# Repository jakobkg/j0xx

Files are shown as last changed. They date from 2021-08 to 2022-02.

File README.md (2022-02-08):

# j0xx
A controller inspired by the Frame1 and Smashbox controllers
image of the controller

## Case
### BOM
 - 36 M2 screws, countersunk head recommended
   - 28x 10mm
   - 8x 5mm
 - 18 M2 threaded spacers
   - 18x 10mm
 - 35 pieces of wire, stranded or solid core

## PCBs
The PCB files in this repository are all made using KiCad 6, and may not work properly in earlier versions. Most files are only plain PCBs, but the "main board" files also hold part numbers and information needed to place an order including assembly through JLCPCB.

## Build notes
***Due to height constraints, surface mounted LEDs can not be used along with low profile Choc switches in this iteration of the design***

The controller case is designed to be made out of cut sheets of material, such as laser cut wood/acrylic or metal.
I recommend a thickness of 3mm for the top plate for use with low profile Choc switches, and 6mm for use with regular MX switches to ensure keycaps protrude nicely without the sides of the switches being exposed.
The switch mounting plate needs to be 1.5mm thick to fit the Cherry MX/Kailh Choc design specs and ensure a good fit, thinner plates may cause poor mounting and thicker plates will interfere with Choc switch mounting.

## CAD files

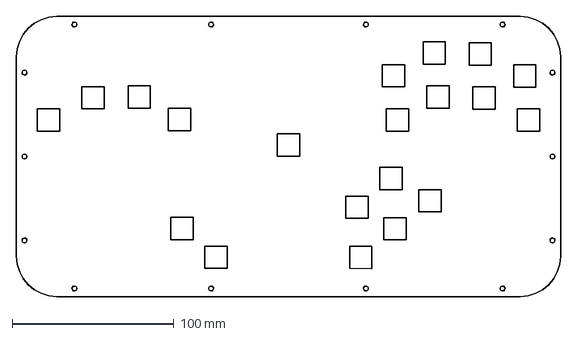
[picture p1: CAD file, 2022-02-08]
case/switchplate_choc.dxf
336.4 x 173.2 mm

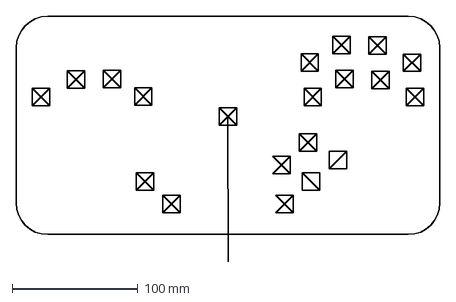
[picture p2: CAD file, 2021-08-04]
switchplate.dxf
336.4 x 194.8 mm

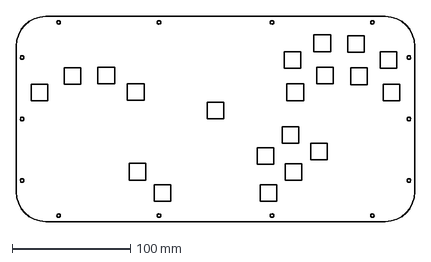
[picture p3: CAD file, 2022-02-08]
case/switchplate_MX.dxf
336.4 x 173.2 mm

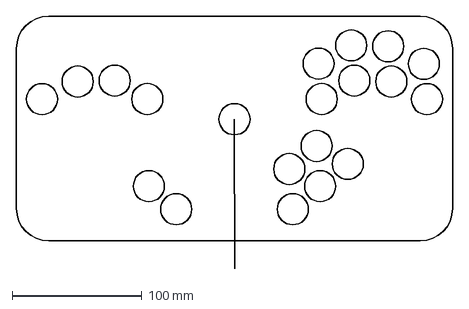
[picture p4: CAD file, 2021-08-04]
top.dxf
336.4 x 194.8 mm

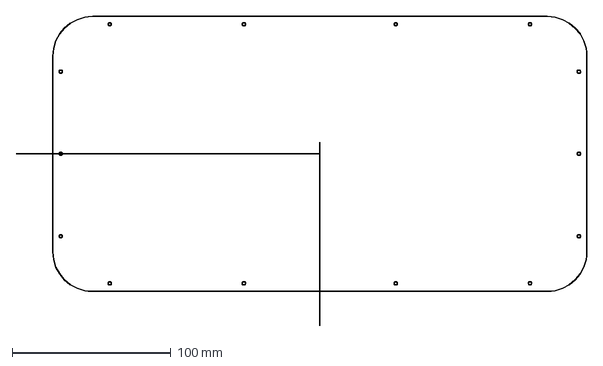
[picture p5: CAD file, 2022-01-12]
case/bottom.dxf
359.5 x 194.8 mm

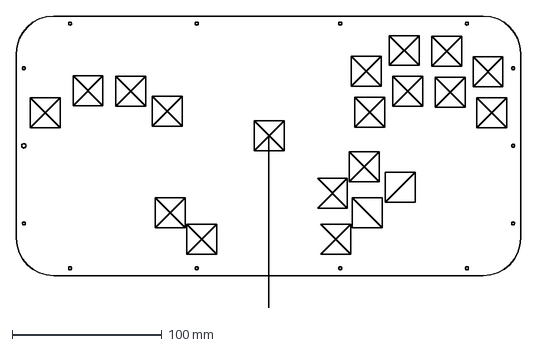
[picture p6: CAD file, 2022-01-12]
case/top.dxf
336.4 x 194.8 mm

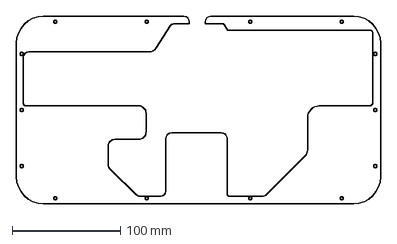
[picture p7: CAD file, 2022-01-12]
case/body.dxf
336.4 x 173.2 mm

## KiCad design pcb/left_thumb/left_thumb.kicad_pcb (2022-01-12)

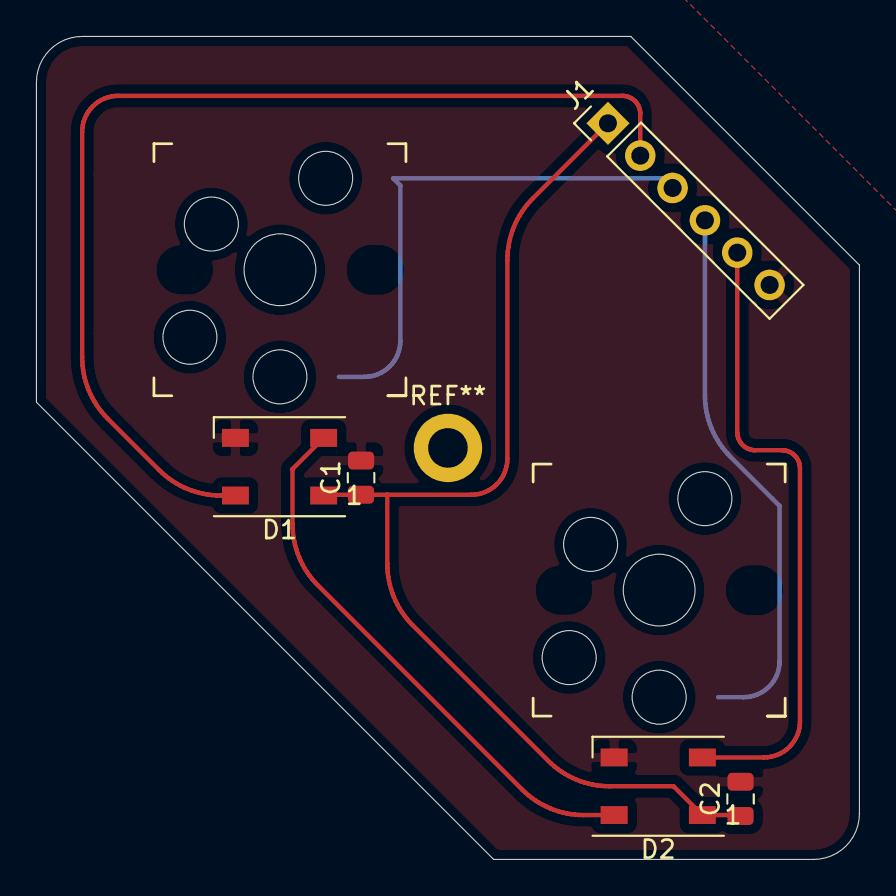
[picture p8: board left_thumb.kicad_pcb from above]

Board: 2 copper layers, 45.7 x 45.7 mm, 7 parts (0 on the bottom side), 7 nets.

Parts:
C1, C2: C; C_0805_2012Metric
D1, D2: WS2812B; LED_WS2812B_PLCC4_5.0x5.0mm_P3.2mm
J1: Conn_01x06; PinHeader_1x06_P2.54mm_Vertical
SW1, SW2: SW_Push; MX+Choc_socket

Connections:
+5V: C1.1, C2.1, D1.1, D2.1, J1.1
BTN_MODX: J1.3, SW1.1
BTN_MODY: J1.4, SW2.1
GND: C1.2, C2.2, D1.3, D2.3, J1.6, SW1.2, SW2.2
LED_IN: D1.4, J1.2
LED_OUT: D2.2, J1.5
unnamed: D1.2, D2.4

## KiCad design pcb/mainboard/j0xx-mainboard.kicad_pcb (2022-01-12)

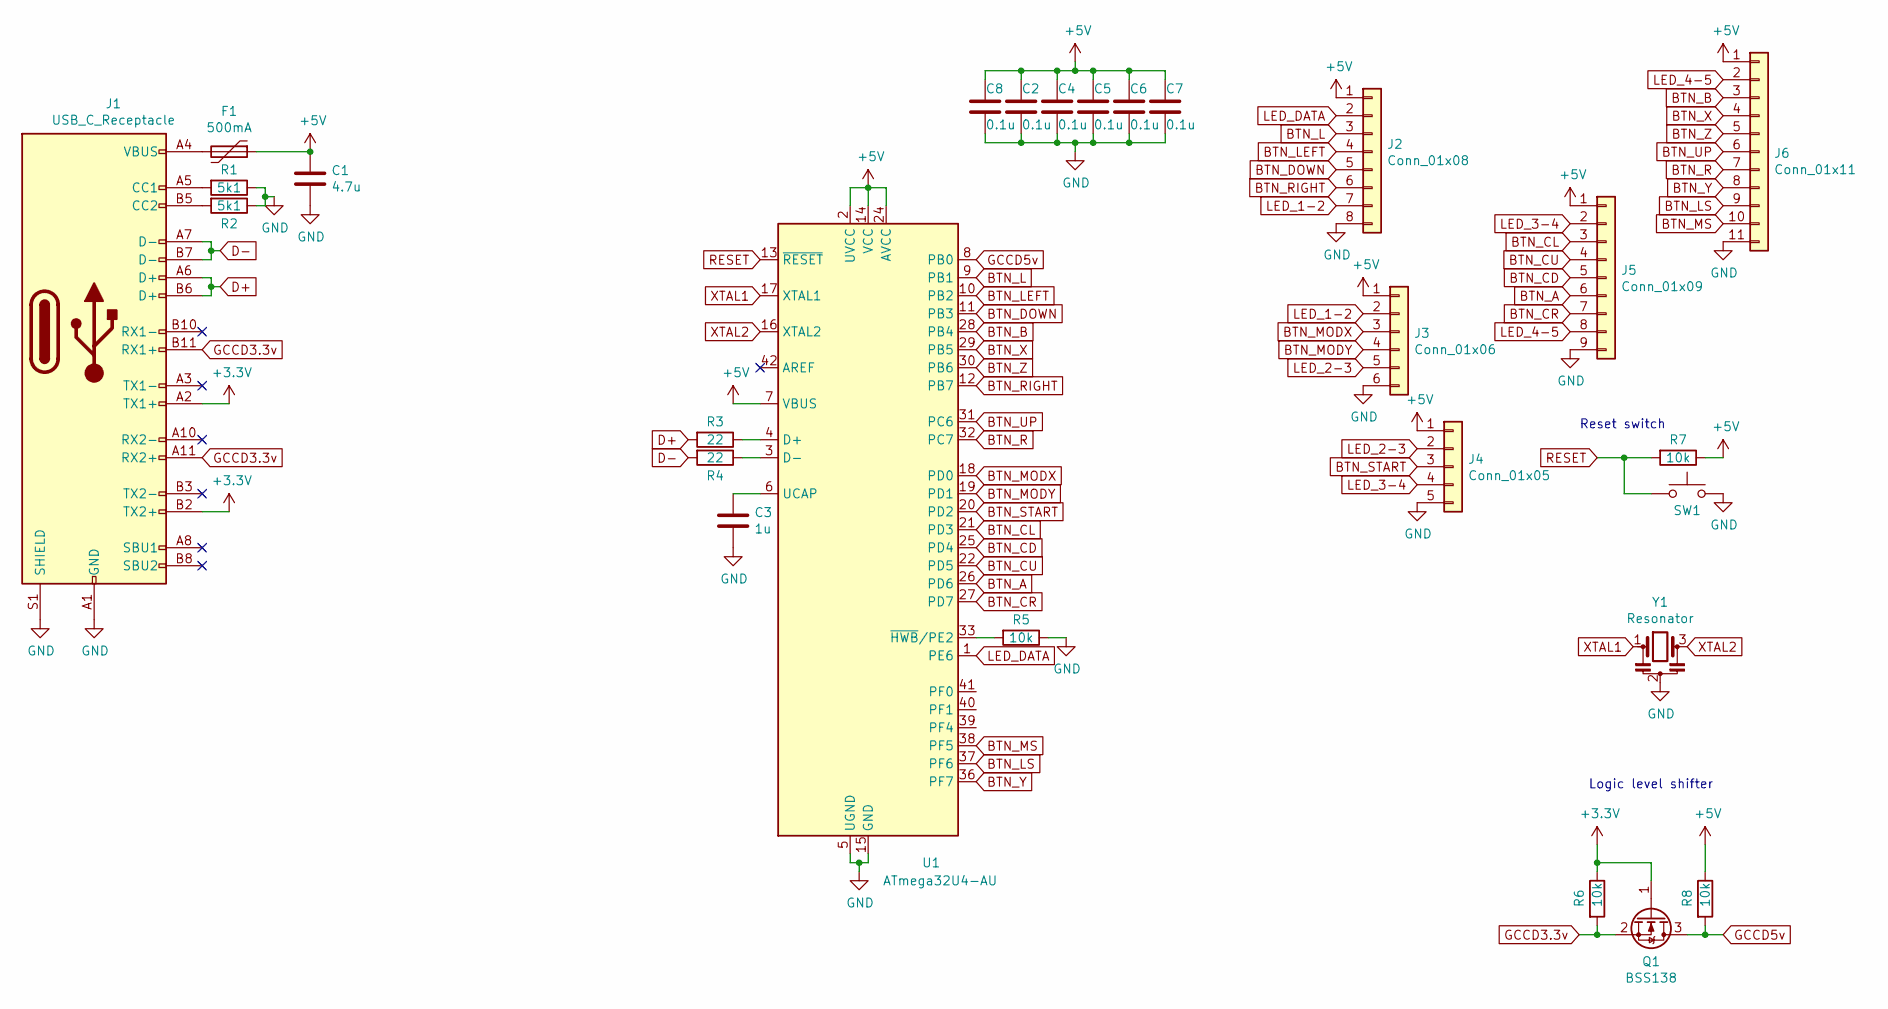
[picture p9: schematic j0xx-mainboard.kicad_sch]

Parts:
C1: 4.7u; C_0805_2012Metric; LCSC C1779
C2, C4, C5, C6, C7, C8: 0.1u; C_0805_2012Metric; LCSC C28233
C3: 1u; C_0805_2012Metric; LCSC C28323
F1: 500mA; Fuse_1206_3216Metric; LCSC C261952
J1: USB_C_Receptacle; USB_C_LCSC_C456013; LCSC C456013
J2: Conn_01x08; PinHeader_1x08_P2.54mm_Vertical
J3: Conn_01x06; PinHeader_1x06_P2.54mm_Vertical
J4: Conn_01x05; PinHeader_1x05_P2.54mm_Vertical
J5: Conn_01x09; PinHeader_1x09_P2.54mm_Vertical
J6: Conn_01x11; PinHeader_1x11_P2.54mm_Vertical
Q1: BSS138; SOT-23; LCSC C427380
R1, R2: 5k1; R_0805_2012Metric; LCSC C27834
R3, R4: 22; R_0805_2012Metric; LCSC C17561
R5, R6, R7, R8: 10k; R_0805_2012Metric; LCSC C17414
SW1: reset; TestPoint_2Pads_Pitch2.54mm_Drill0.8mm
U1: ATmega32U4-AU; TQFP-44_10x10mm_P0.8mm; LCSC C112161
Y1: Resonator; Resonator_SMD_Murata_CSTxExxV-3Pin_3.0x1.1mm; LCSC C341521

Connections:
+3V3: J1.A2 (TX1+), J1.B2 (TX2+), Q1.1 (G), R6.1
+5V: C1.1, C2.1, C4.1, C5.1, C6.1, C7.1, C8.1, F1.1, J2.1, J3.1, J4.1, J5.1, J6.1, R7.1, R8.1, U1.2 (UVCC), U1.7 (VBUS), U1.14 (VCC), U1.24 (AVCC), U1.34 (VCC), U1.44 (AVCC)
BTN_A: J5.6, U1.26 (PD6)
BTN_B: J6.3, U1.28 (PB4)
BTN_CD: J5.5, U1.25 (PD4)
BTN_CL: J5.3, U1.21 (PD3)
BTN_CR: J5.7, U1.27 (PD7)
BTN_CU: J5.4, U1.22 (PD5)
BTN_DOWN: J2.5, U1.11 (PB3)
BTN_L: J2.3, U1.9 (PB1)
BTN_LEFT: J2.4, U1.10 (PB2)
BTN_LS: J6.9, U1.37 (PF6)
BTN_MODX: J3.3, U1.18 (PD0)
BTN_MODY: J3.4, U1.19 (PD1)
BTN_MS: J6.10, U1.38 (PF5)
BTN_R: J6.7, U1.32 (PC7)
BTN_RIGHT: J2.6, U1.12 (PB7)
BTN_START: J4.3, U1.20 (PD2)
BTN_UP: J6.6, U1.31 (PC6)
BTN_X: J6.4, U1.29 (PB5)
BTN_Y: J6.8, U1.36 (PF7)
BTN_Z: J6.5, U1.30 (PB6)
D+: J1.A6 (D+), J1.B6 (D+), R3.2
D-: J1.A7 (D-), J1.B7 (D-), R4.2
GCCD3.3v: J1.A11 (RX2+), J1.B11 (RX1+), Q1.2 (S), R6.2
GCCD5v: Q1.3 (D), R8.2, U1.8 (PB0)
GND: C1.2, C2.2, C3.2, C4.2, C5.2, C6.2, C7.2, C8.2, J1.A1 (GND), J1.A12 (GND), J1.B1 (GND), J1.B12 (GND), J1.S1 (SHIELD), J2.8, J3.6, J4.5, J5.9, J6.11, R1.1, R2.1, R5.1, SW1.2, U1.5 (UGND), U1.15 (GND), U1.23 (GND), U1.35 (GND), U1.43 (GND), Y1.2
LED_1-2: J2.7, J3.2
LED_2-3: J3.5, J4.2
LED_3-4: J4.4, J5.2
LED_4-5: J5.8, J6.2
LED_DATA: J2.2, U1.1 (PE6)
unnamed: C3.1, U1.6 (UCAP)
unnamed: F1.2, J1.A4 (VBUS), J1.A9 (VBUS), J1.B4 (VBUS), J1.B9 (VBUS)
unnamed: J1.A5 (CC1), R1.2
unnamed: J1.B5 (CC2), R2.2
unnamed: R3.1, U1.4 (D+)
unnamed: R4.1, U1.3 (D-)
unnamed: R5.2, U1.33 (~HWB/PE2)
RESET: R7.2, SW1.1, U1.13 (~RESET)
XTAL1: U1.17 (XTAL1), Y1.1
XTAL2: U1.16 (XTAL2), Y1.3

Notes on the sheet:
Logic level shifter
Reset switch

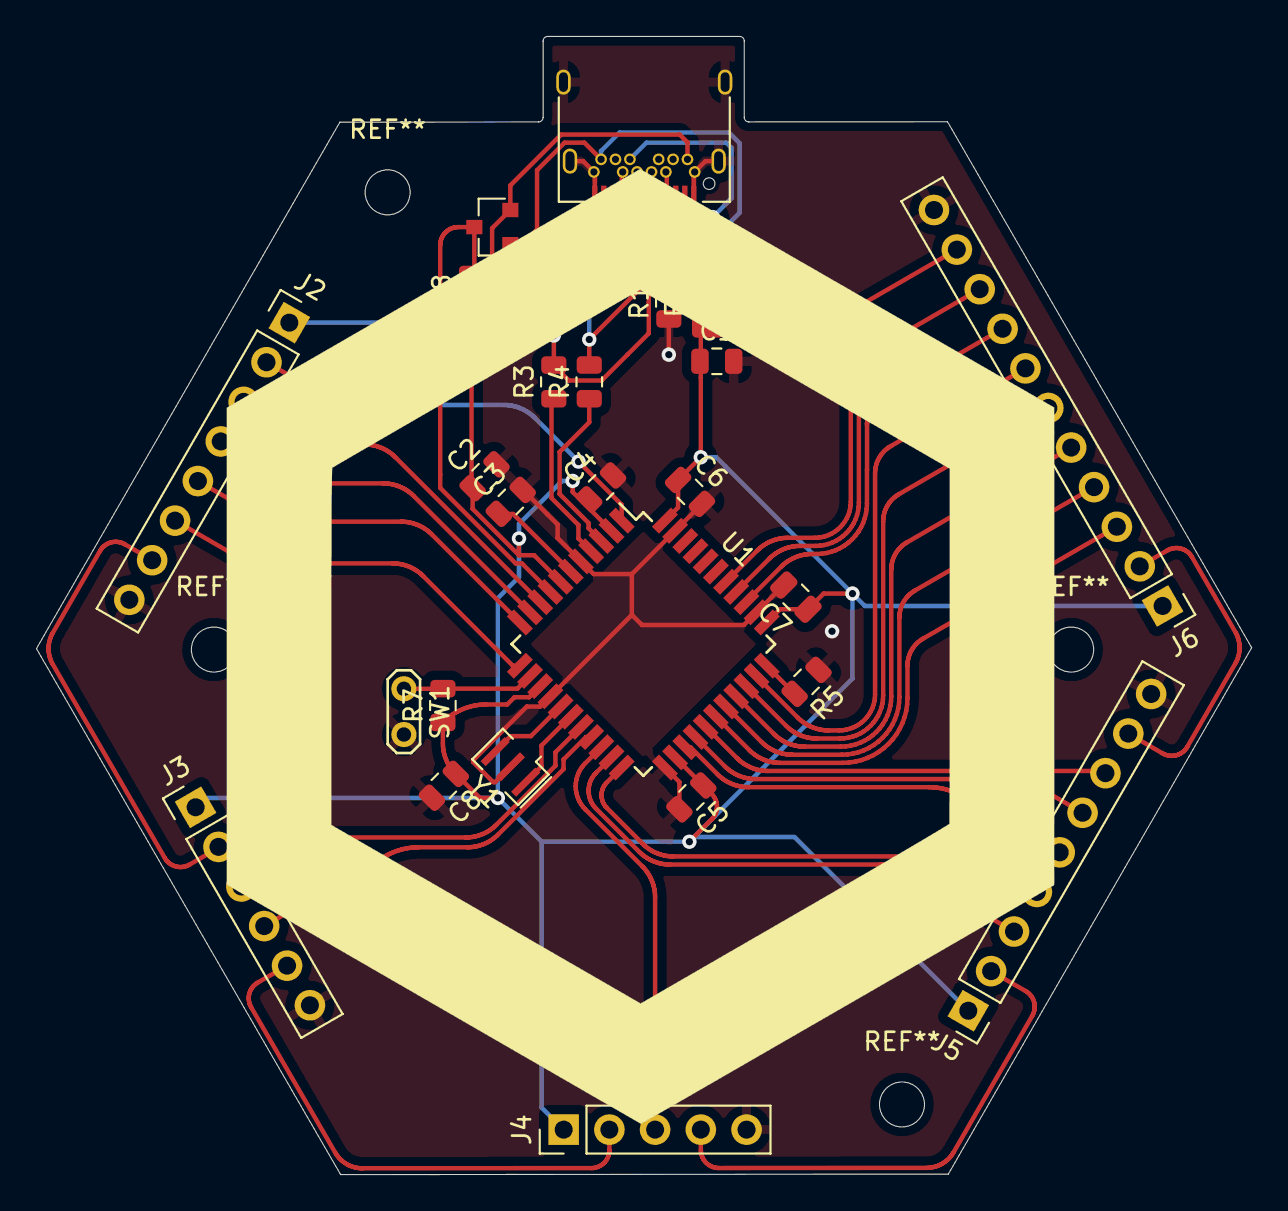
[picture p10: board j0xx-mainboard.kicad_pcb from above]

Board: 2 copper layers, 67.5 x 63.2 mm, 27 parts (0 on the bottom side), 42 nets.

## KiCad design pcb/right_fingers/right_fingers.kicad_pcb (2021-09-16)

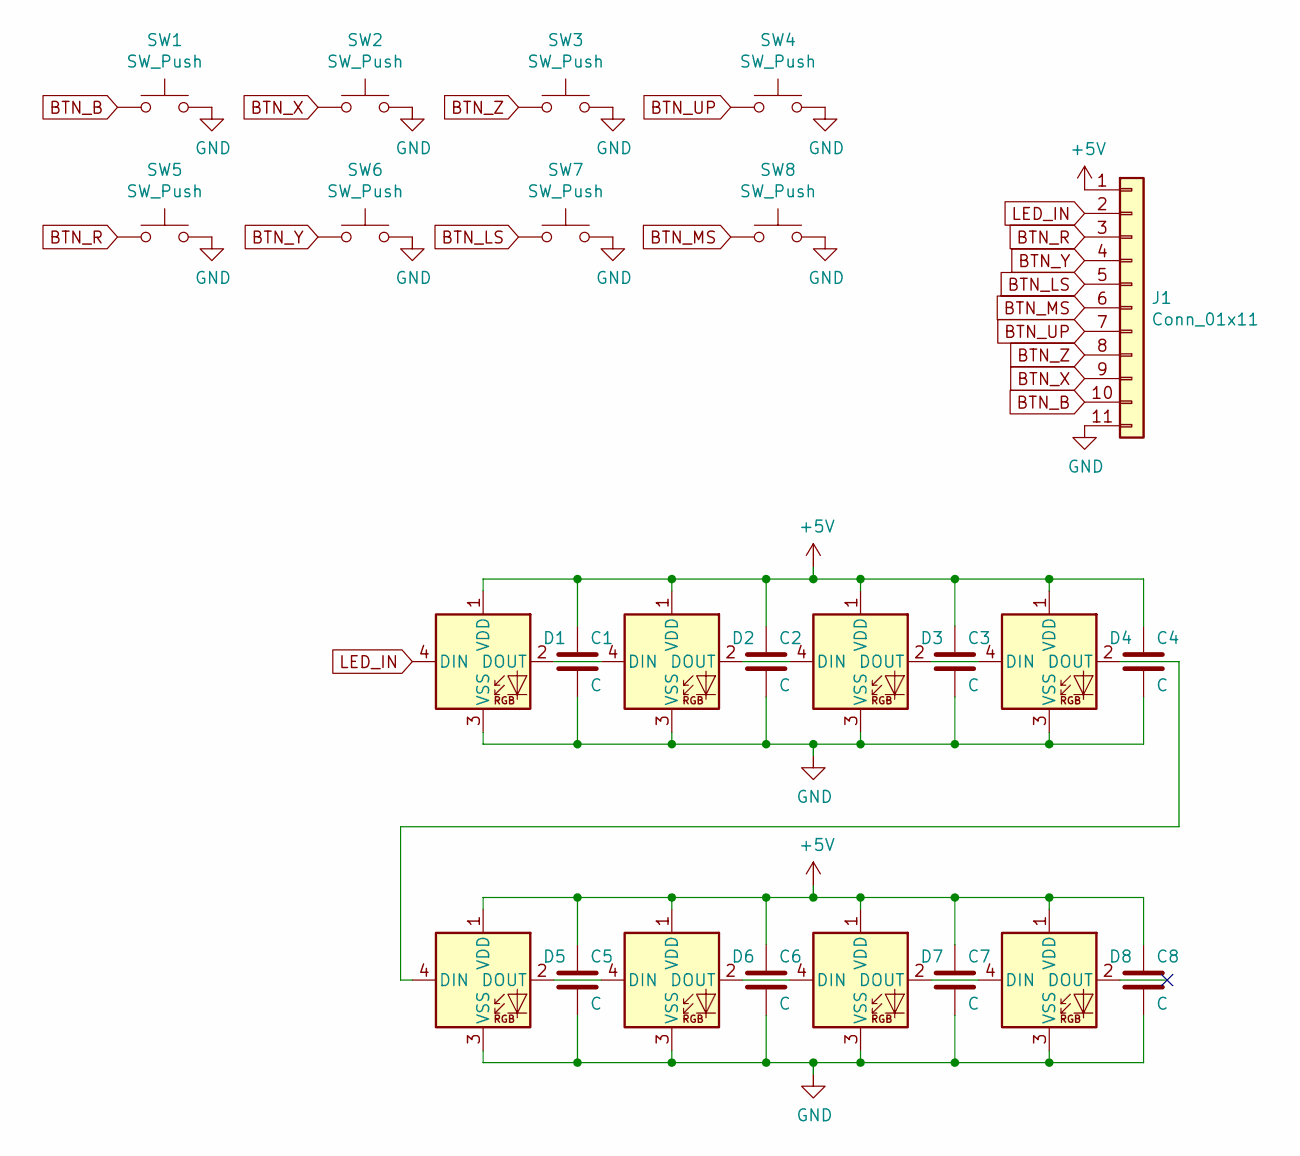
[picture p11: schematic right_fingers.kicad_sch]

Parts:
C1, C2, C3, C4, C5, C6, C7, C8: C; C_0805_2012Metric
D1, D2, D3, D4, D5, D6, D7, D8: WS2812B; LED_WS2812B_PLCC4_5.0x5.0mm_P3.2mm
J1: Conn_01x11; PinHeader_1x11_P2.54mm_Vertical
SW1, SW2, SW3, SW4, SW5, SW6, SW7, SW8: SW_Push; MX+Choc_socket

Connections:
+5V: C1.1, C2.1, C3.1, C4.1, C5.1, C6.1, C7.1, C8.1, D1.1 (VDD), D2.1 (VDD), D3.1 (VDD), D4.1 (VDD), D5.1 (VDD), D6.1 (VDD), D7.1 (VDD), D8.1 (VDD), J1.1
BTN_B: J1.10, SW1.1
BTN_LS: J1.5, SW7.1
BTN_MS: J1.6, SW8.1
BTN_R: J1.3, SW5.1
BTN_UP: J1.7, SW4.1
BTN_X: J1.9, SW2.1
BTN_Y: J1.4, SW6.1
BTN_Z: J1.8, SW3.1
GND: C1.2, C2.2, C3.2, C4.2, C5.2, C6.2, C7.2, C8.2, D1.3 (VSS), D2.3 (VSS), D3.3 (VSS), D4.3 (VSS), D5.3 (VSS), D6.3 (VSS), D7.3 (VSS), D8.3 (VSS), J1.11, SW1.2, SW2.2, SW3.2, SW4.2, SW5.2, SW6.2, SW7.2, SW8.2
LED_IN: D1.4 (DIN), J1.2
unnamed: D1.2 (DOUT), D2.4 (DIN)
unnamed: D2.2 (DOUT), D3.4 (DIN)
unnamed: D3.2 (DOUT), D4.4 (DIN)
unnamed: D4.2 (DOUT), D5.4 (DIN)
unnamed: D5.2 (DOUT), D6.4 (DIN)
unnamed: D6.2 (DOUT), D7.4 (DIN)
unnamed: D7.2 (DOUT), D8.4 (DIN)

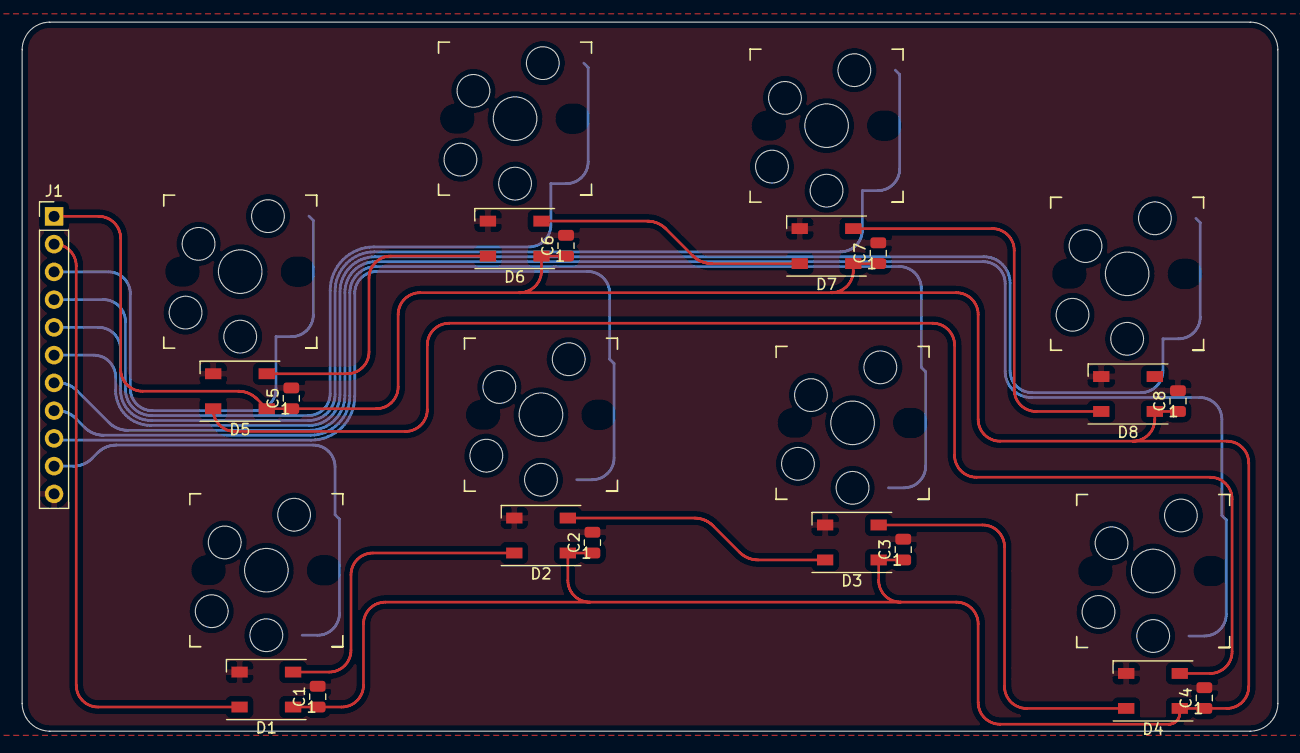
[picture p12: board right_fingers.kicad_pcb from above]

Board: 2 copper layers, 114.9 x 64.9 mm, 25 parts (0 on the bottom side), 18 nets.

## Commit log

2021-08-04 move pcb files a dir up
    [j0xx.kicad_pcb, j0xx.sch]
2021-08-04 added footprints
    [j0xx.sch]
2021-08-05 Initial PCB work
    [j0xx.sch]
2021-08-07 More PCB work, rearrange some MCU pins
    [j0xx.sch]
2021-08-08 First PCB draft complete
    [j0xx.kicad_pcb, j0xx.sch]
2021-08-09 Add dual hotswap footprint
    [j0xx.kicad_pcb, j0xx.sch]
2021-08-10 Start splitting PCB into modules
    [j0xx-mainboard.kicad_pcb, j0xx-mainboard.sch, j0xx.kicad_pcb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]
2021-08-20 rearrange parts, add connectors and outline
    [j0xx-mainboard.kicad_pcb, j0xx-mainboard.sch]
2021-08-22 Protruding USB port, tilted MCU
    [j0xx-mainboard.kicad_pcb]
2021-09-15 Add most PCB modules
    [j0xx-mainboard.kicad_pcb, j0xx-mainboard.sch, left_fingers.kicad_pcb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]
2021-09-16 Finish button cluster PCB drafts
    [left_fingers.kicad_pcb, left_thumb.kicad_pcb, right_fingers.kicad_pcb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]
2022-01-12 First full iteration of physical design
    [body.dxf, bottom.dxf, j0xx-mainboard.kicad_pcb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]
2022-02-08 add MX switch plate, fix mis-sized screw hole
    [switchplate.dxf, switchplate_MX.dxf, switchplate_choc.dxf]
